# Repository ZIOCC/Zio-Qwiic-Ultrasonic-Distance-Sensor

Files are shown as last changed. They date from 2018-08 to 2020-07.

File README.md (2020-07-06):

# Zio Qwiic Ultrasonic Distance Sensor (HC-SR04)

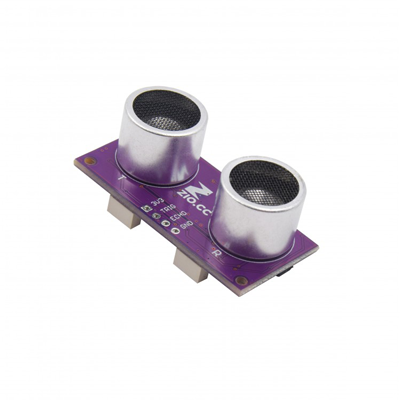
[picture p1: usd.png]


> This product can be available for purchase [here](https://www.smart-prototyping.com/Zio-Ultrasonic-Distance-Sensor.html).

#### Description

This is a [Qwiic](https://www.smart-prototyping.com/Qwiic.html) I2C version of ultrasonic sensor in our Qwiic family. TOF sensor is great, precise and fast, but this Ultrasonic sensor can provide wider detecting angle than TOF sensor and longer distance (3-400cm).

With this module we used a STM8 MCU as gateway to deal with sensor’s digital data in MCU, and send it out via I2C. So you don’t need to care about how it works inside the STM8, just trade it as an I2C device. In case you are interesting, you can check out the STM8 code at the bottom of the links.

We also break the serial pins just like the normal HC-SR04 module. The pins are not pre-soldered. We use an MCU (ATTINY85-20SU) as gateway to turn it into an I2C device.

For additional information on how the Ultrasonic sensor works, you can check out this [page](http://arduinoinfo.mywikis.net/wiki/UltraSonicDistance)!

Note: Try to avoid touching the pins and pads on the backside, the sensor measurement is based on analog single, touching these pins and pads will make the result unstable. 

#### Specification

* Operating Voltage: 3.3V
* Detecting Angle: 15 degree
* Sensor range: 2cm to 400cm
* Accuracy: 3mm
* MCU on board: STM8L051
* I2C Address: 0x00
* Dimension: 21.5x 45.5mm
* Weight: 9.2g

#### Links

* [Eagle File](https://github.com/ZIOCC/Zio-Qwiic-Ultrasonic-Distance-Sensor/)
* [Example Code](https://github.com/ZIOCC/Zio-Qwiic-Ultrasonic-Distance-Sensor/tree/master/Arduino)

###### About Zio
> Zio is a new line of open sourced, compact, and grid layout boards, fully integrated for Arduino and Qwiic ecosystem. Designed ideally for wearables, robotics, small-space limitations or other on the go projects. Check out other awesome Zio products [here](https://www.smart-prototyping.com/Zio).

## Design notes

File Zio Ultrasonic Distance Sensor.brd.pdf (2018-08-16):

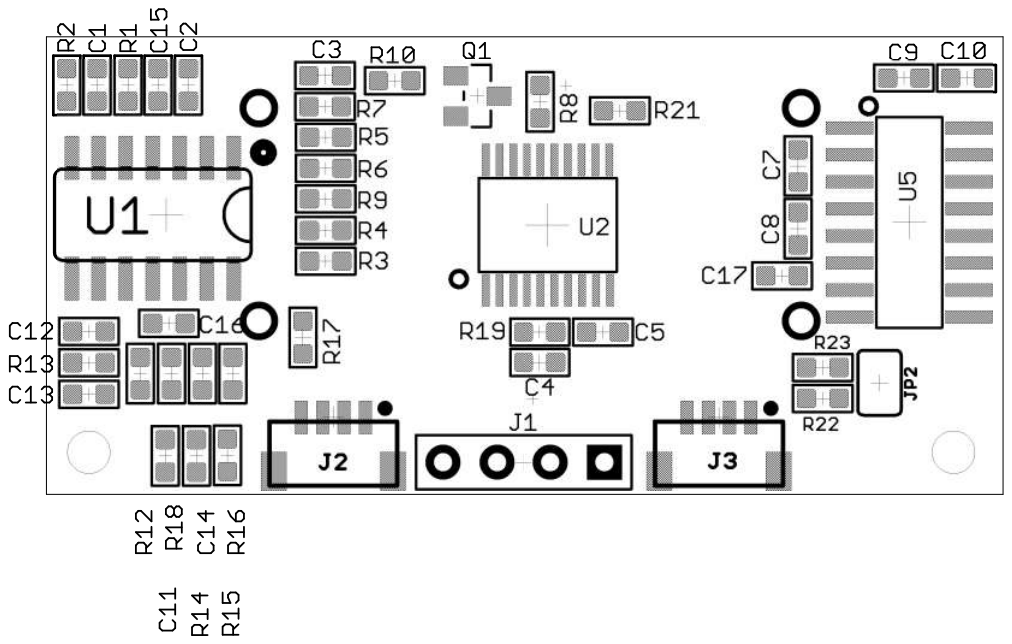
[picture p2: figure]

2018-07-04 19:09 f=3.00 D:\Webshop PCB\Zio Ultrasonic Distance Sensor\EAGLE\Zio Ultrasonic Distance Sensor.brd

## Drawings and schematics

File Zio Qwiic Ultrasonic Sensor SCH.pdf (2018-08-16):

# STM8 V⁺ V-

+3V3 1K ±1%

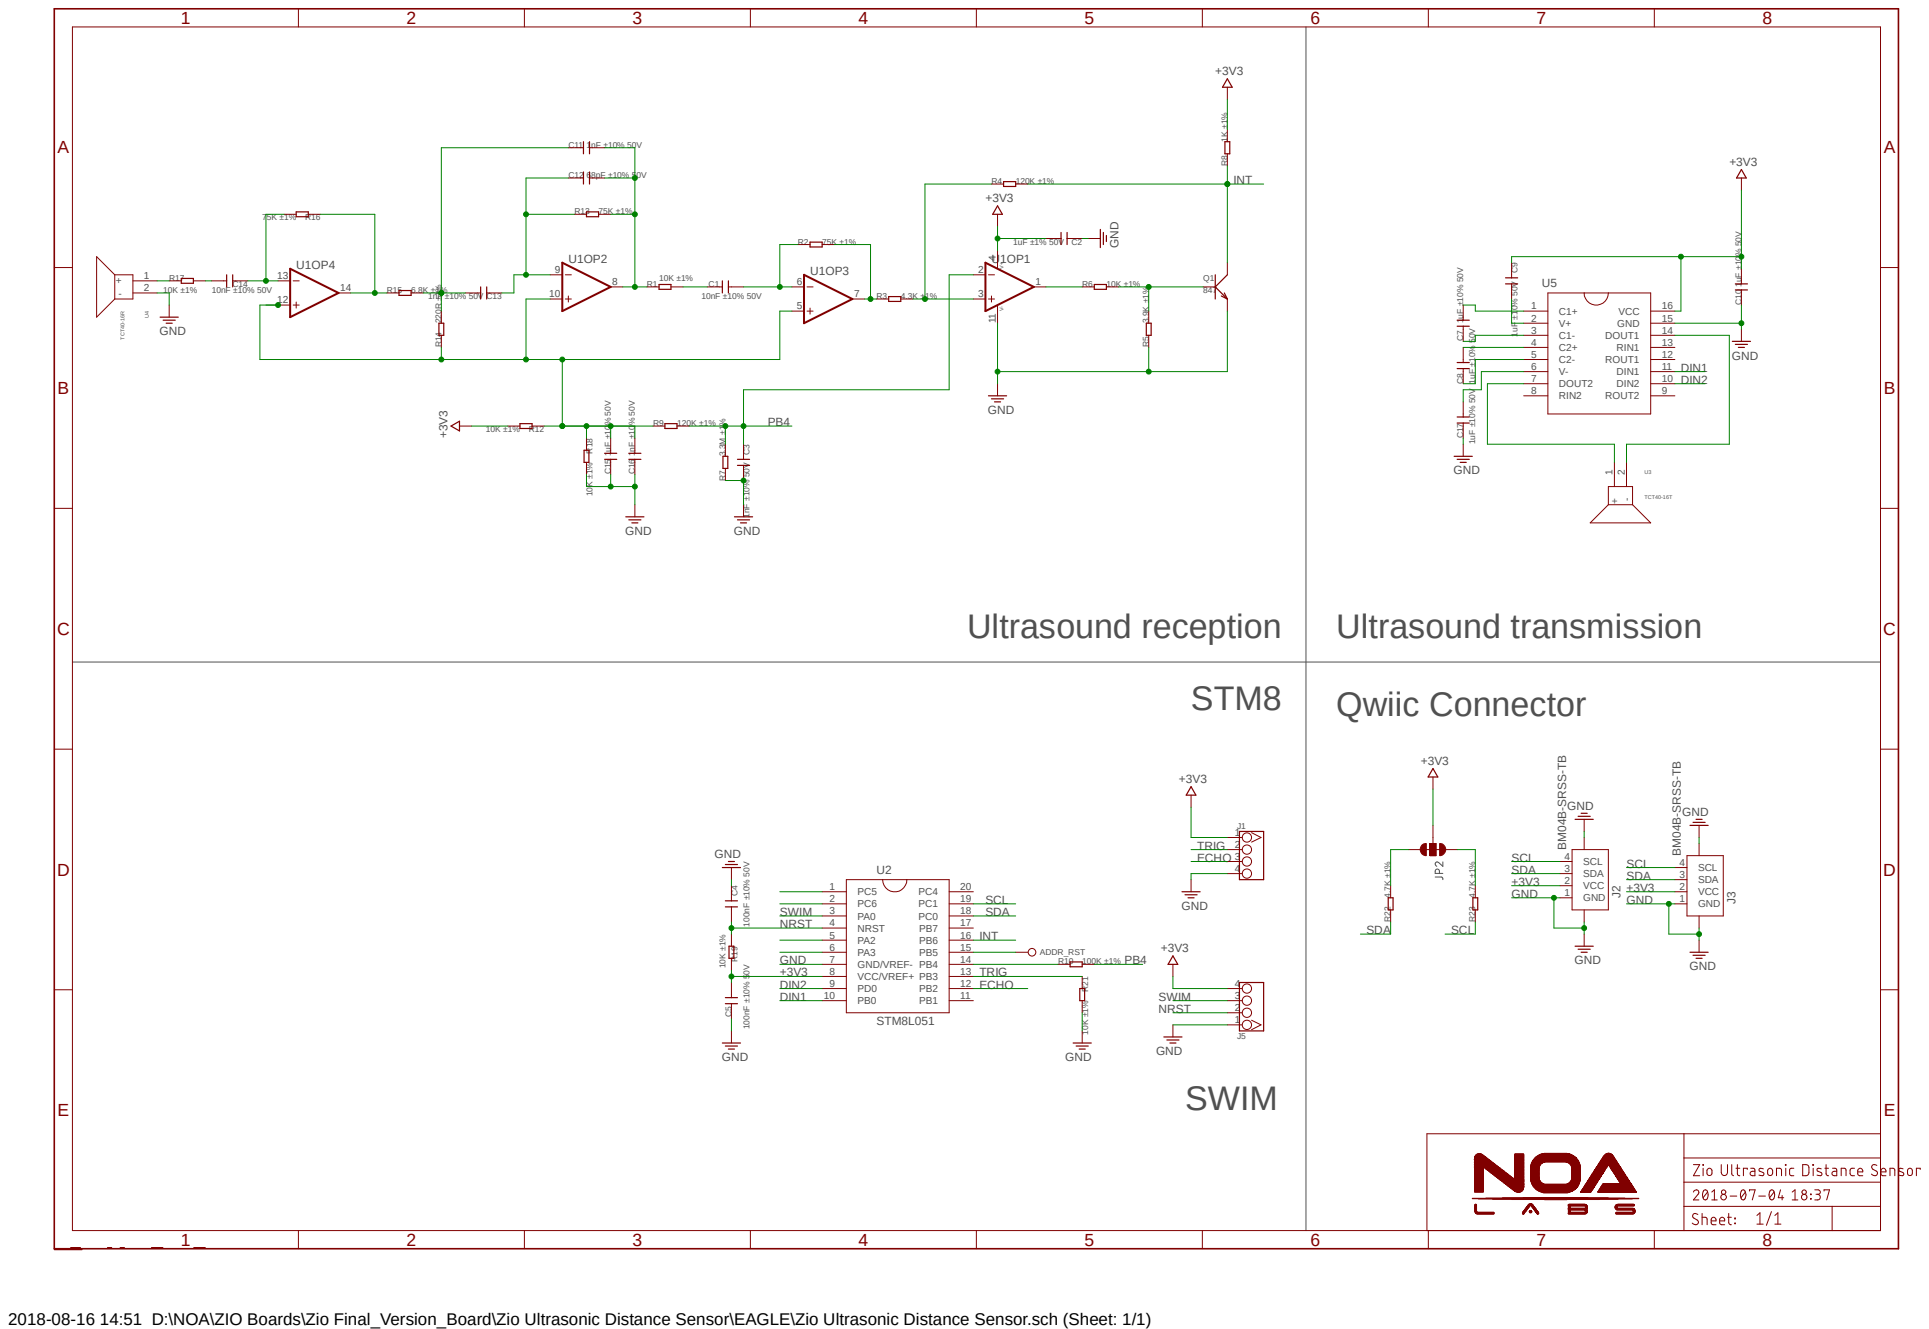
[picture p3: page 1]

2018-08-16 14:51 D:\NOA\ZIO Boards\Zio Final_Version_Board\Zio Ultrasonic Distance Sensor\EAGLE\Zio Ultrasonic Distance Sensor.sch (Sheet: 1/1)

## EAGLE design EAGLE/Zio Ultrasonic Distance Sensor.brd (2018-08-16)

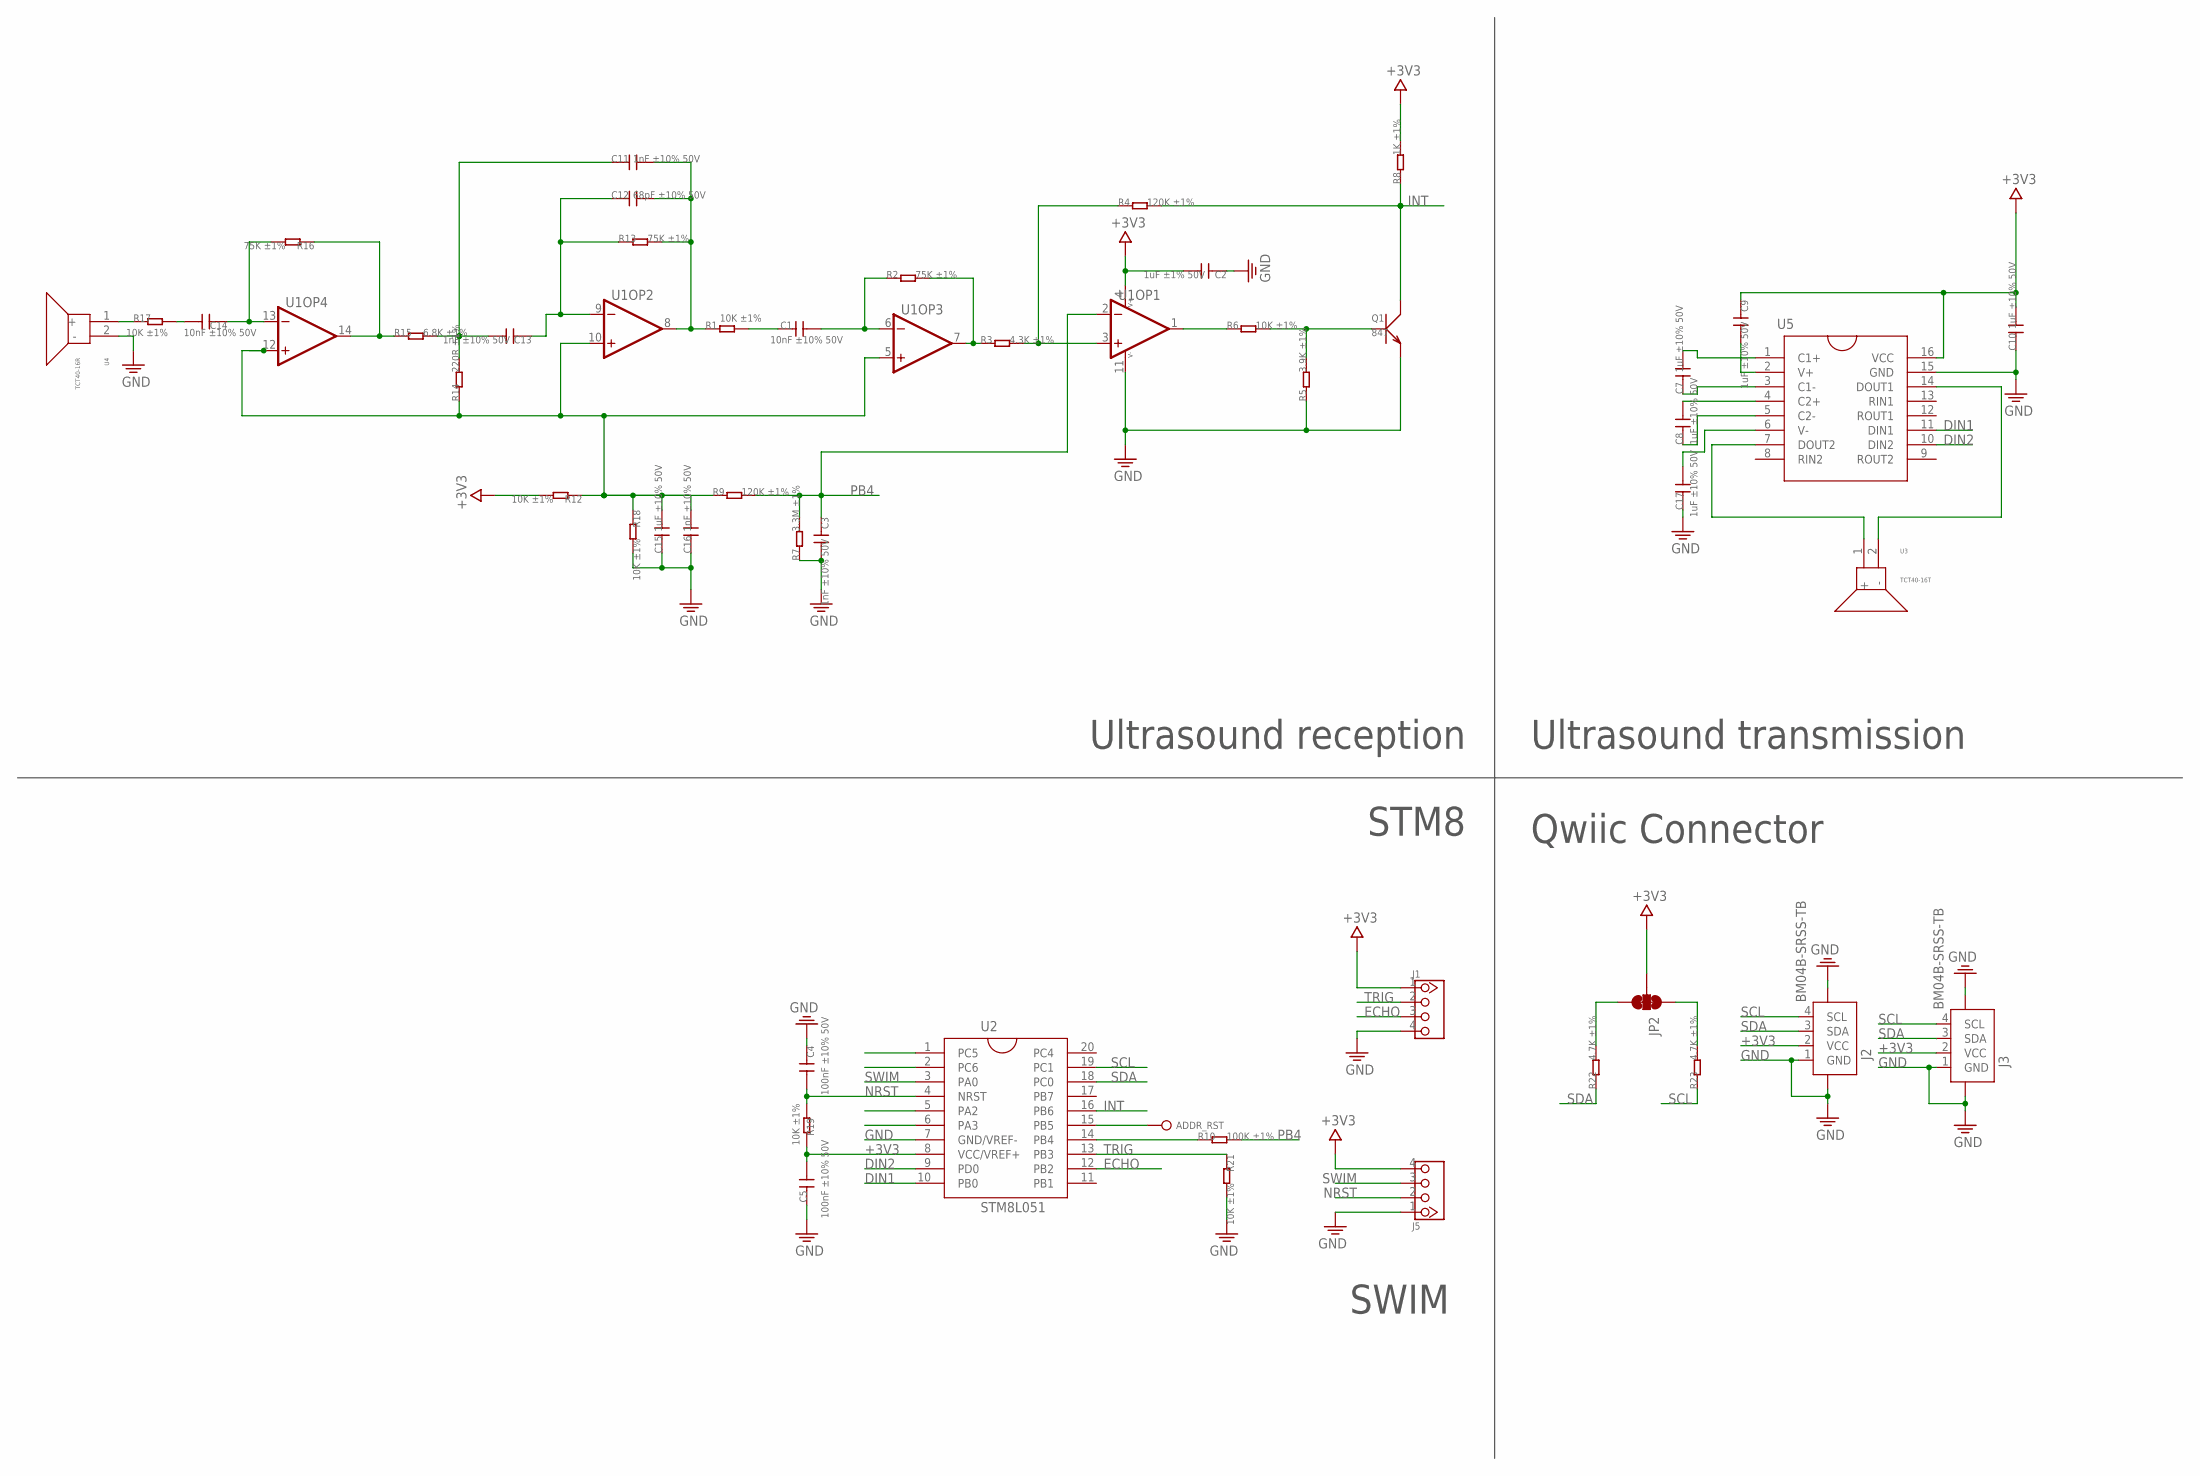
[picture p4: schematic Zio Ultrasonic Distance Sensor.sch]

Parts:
ADDR_RST: TEST_POINT35MIL; 1P-35MIL
C1, C14: 10nF ±10% 50V; 0603
C2: 1uF ±1% 50V; 0603
C3, C11, C13, C16: 1nF ±10% 50V; 0603
C4, C5: 100nF ±10% 50V; 0603
C7, C8, C9, C10, C15, C17: 1uF ±10% 50V; 0603
C12: 68pF ±10% 50V; 0603
J1: HEADER-4P-60/35MIL; 4P-65/35MIL
J2, J3: BM04B-SRSS-TB; JST-SH-4P-90
J5: HEADER-4P-TEST_3.08_4P; TEST_3.08_4P
JP2: SMT-JUMPER_3_2-NC_TRACE
Q1: 847; SOT23
R1, R6, R12, R17, R18, R19, R21: 10K ±1%; 0603
R2, R13, R16: 75K ±1%; 0603
R3: 4.3K ±1%; 0603
R4, R9: 120K ±1%; 0603
R5: 3.9K ±1%; 0603
R7: 3.3M ±1%; 0603
R8: 1K ±1%; 0603
R10: 100K ±1%; 0603
R14: 220R ±1%; 0603
R15: 6.8K ±1%; 0603
R22, R23: 4.7K ±1%; 0603
U1: LMV324; SO014
U2: STM8L051; TSSOP20
U3: TCT40-16T; TCT40-16T/R
U4: TCT40-16R; TCT40-16T/R
U5: UT3232G-S16-RSOIC-16; SOIC16

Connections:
+3V3: C2.2, C5.1, C9.1, C10.2, J1.1, J2.2 (VCC), J3.2 (VCC), J5.4, JP2.2, R8.2, R12.2, R19.2, U1.4 (V+), U2.8 (VCC/VREF+), U5.16 (VCC)
DIN1: U2.10 (PB0), U5.11 (DIN1)
DIN2: U2.9 (PD0), U5.10 (DIN2)
ECHO: J1.3, U2.12 (PB2)
GND: C2.1, C3.2, C4.1, C5.2, C10.1, C15.1, C16.1, C17.1, J1.4, J2.1 (GND), J2.5, J2.6, J3.1 (GND), J3.5, J3.6, J5.1, Q1.2 (E), R5.1, R7.1, R18.2, R21.2, U1.11 (V-), U2.7 (GND/VREF-), U4.2 (-), U5.15 (GND)
INT: Q1.3 (C), R4.2, R8.1, U2.16 (PB6)
unnamed: R2.2, R3.1, U1.7 (OUT)
unnamed: C1.1, R2.1, U1.6 (IN-)
unnamed: C1.2, R1.2
unnamed: R3.2, R4.1, U1.3 (IN+)
unnamed: Q1.1 (B), R5.2, R6.2
unnamed: R6.1, U1.1 (OUT)
unnamed: C7.2, U5.1 (C1+)
unnamed: C12.1, C13.1, R13.1, U1.9 (IN-)
unnamed: C11.2, C12.2, R1.1, R13.2, U1.8 (OUT)
unnamed: C15.2, C16.2, R9.1, R12.1, R14.1, R18.1, U1.5 (IN+), U1.10 (IN+), U1.12 (IN+)
unnamed: C11.1, C13.2, R14.2, R15.2
unnamed: C7.1, U5.3 (C1-)
unnamed: R15.1, R16.1, U1.14 (OUT)
unnamed: C14.1, R16.2, U1.13 (IN-)
unnamed: C14.2, R17.2
unnamed: C8.2, U5.4 (C2+)
unnamed: C8.1, U5.5 (C2-)
unnamed: JP2.3, R22.2
unnamed: JP2.1, R23.2
unnamed: C9.2, U5.2 (V+)
unnamed: C17.2, U5.6 (V-)
unnamed: U3.2 (-), U5.14 (DOUT1)
unnamed: U3.1 (+), U5.7 (DOUT2)
unnamed: R17.1, U4.1 (+)
unnamed: ADDR_RST.P$1, U2.15 (PB5)
unnamed: R10.1, U2.14 (PB4)
NRST: C4.2, J5.2, R19.1, U2.4 (NRST)
PB4: C3.1, R7.2, R9.2, R10.2, U1.2 (IN-)
SCL: J2.4 (SCL), J3.4 (SCL), R23.1, U2.19 (PC1)
SDA: J2.3 (SDA), J3.3 (SDA), R22.1, U2.18 (PC0)
SWIM: J5.3, U2.3 (PA0)
TRIG: J1.2, R21.1, U2.13 (PB3)

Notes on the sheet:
SWIM
Qwiic Connector
Ultrasound transmission
Ultrasound reception
STM8

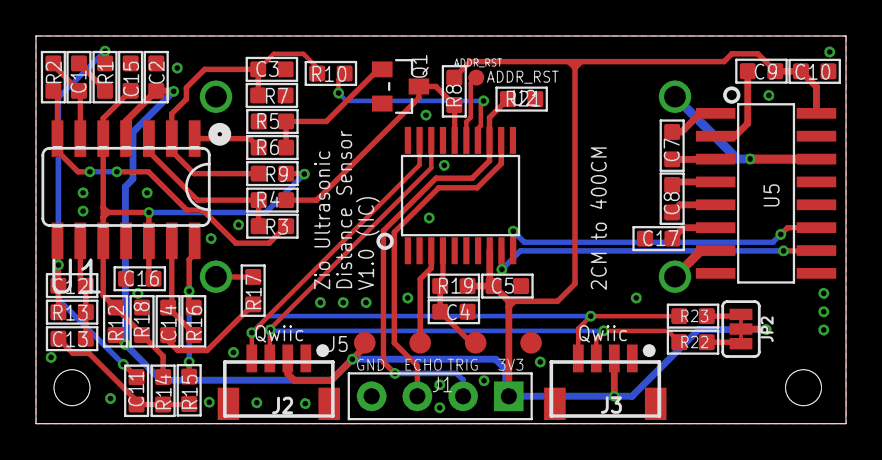
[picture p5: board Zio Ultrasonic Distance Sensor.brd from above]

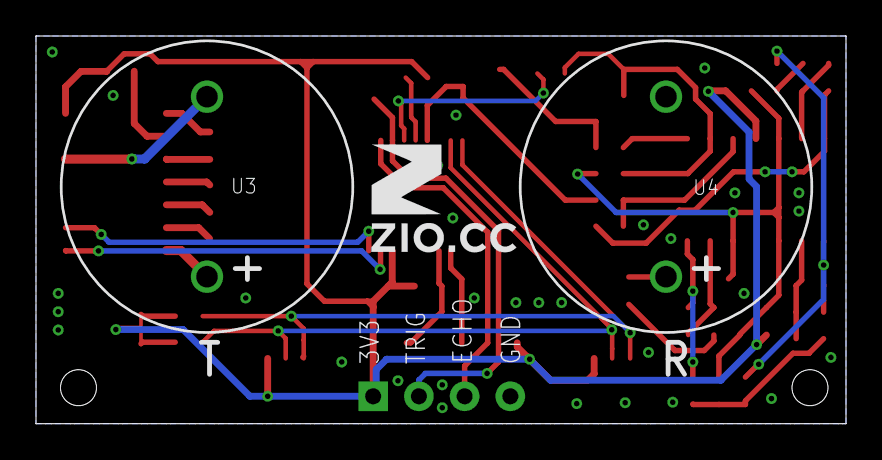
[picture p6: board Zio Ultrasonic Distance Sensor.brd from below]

Board: 2 copper layers, 45.0 x 21.5 mm, 50 parts (3 on the bottom side), 38 nets.

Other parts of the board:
U$5: 6MM

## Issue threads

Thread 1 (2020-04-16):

i2C Address

safariace, 2020-04-16:
I'm using a Raspberry Pi connected to a ZIO Ultrasonic with a qwiic connection.

I2CDetect returns no scan for the HC_SR04.  I see the other i2c devices on the bus, but no the ultrasonic sensor.  The arduino code has these two lines:

#define SLAVE_BROADCAST_ADDR 0x00  //default address
#define SLAVE_ADDR 0x00       //SLAVE_ADDR 0xA0-0xAF

Which implies address 0x00

The comment seems to imply the slave address should be in the range 0xA0-AF  .

AlexChuSmartPrototyping, 2020-06-17:
Hi, the sensor default address is 0x00, this is correct, you can just send the read commend to this address then you will get the distance data. There is way to change the sensor address, but unless there is address conflict, I won't recommend to do so.

JamesB7, 2021-07-15:
A sensor should never use address 0x00. It is reserved for I2C General Calls, which by spec may be used by some devices to configure their addresses (such devices will always be listening on 0x00 as well as their current address).

marvinrobot42, 2024-03-24:
I agree with JamesB7 in that the I2C sensor interface needs its own address, not 0x00 which is the "any address" or broadcast to all devices on bus address.  Hopefully Sparkfun can help with getting your own I2C address.

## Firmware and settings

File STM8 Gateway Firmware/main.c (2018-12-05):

/*******************************************************************************
***********************Zio Ultrasonic Distance Sensor***************************
***********************************ZIO.CC***************************************
*******************************************************************************/



#include "stm8l15x.h"
#include "bsp.h"

#define TIM4_PERIOD       16*10

//#define SLAVE_ADDR 0x00
#define I2CSPEED 400000 //i2c Speed

//extern uint8_t SLAVE_ADDRESS[10]={0xA0,0xA1,0xA2,0xA3,0xA4,0xA5,0xA6,0xA7,0xA8,0xA9};
extern uint8_t SLAVE_ADDRESS=0x00;

extern char SBUF=0;
extern uint16_t measure_flag=0;


/*******************************************************************************
****Parameter In£ºNone
****Parameter Out£ºNone
****Fuction£ºmain
****Author£ºHarry
*******************************************************************************/
int main( void )
{
  CLK_SYSCLKDivConfig(CLK_SYSCLKDiv_1);    
  CLK_SYSCLKSourceConfig(CLK_SYSCLKSource_HSI);
  CLK_HSICmd(ENABLE);                      
  
  GPIO_Init(GPIOB, (GPIO_Pin_TypeDef)GPIO_Pin_0, GPIO_Mode_Out_PP_Low_Fast);
  GPIO_Init(GPIOD, (GPIO_Pin_TypeDef)GPIO_Pin_0, GPIO_Mode_Out_PP_Low_Fast);
  GPIO_Init(GPIOB, (GPIO_Pin_TypeDef)GPIO_Pin_2, GPIO_Mode_Out_PP_Low_Fast);
  GPIO_Init(GPIOB, (GPIO_Pin_TypeDef)GPIO_Pin_4, GPIO_Mode_Out_PP_Low_Fast);
  
  GPIO_Init(GPIOC, (GPIO_Pin_TypeDef)GPIO_Pin_0, GPIO_Mode_Out_PP_High_Fast);
  GPIO_Init(GPIOC, (GPIO_Pin_TypeDef)GPIO_Pin_1, GPIO_Mode_Out_PP_High_Fast);

  GPIO_Init(GPIOB, (GPIO_Pin_TypeDef)GPIO_Pin_3, GPIO_Mode_In_FL_IT);
  GPIO_Init(GPIOB, (GPIO_Pin_TypeDef)GPIO_Pin_6, GPIO_Mode_In_FL_IT);
  GPIO_Init(GPIOB, (GPIO_Pin_TypeDef)GPIO_Pin_5, GPIO_Mode_In_PU_IT);
  
  EXTI_DeInit (); 
  EXTI_SetPinSensitivity (EXTI_Pin_3,EXTI_Trigger_Rising);
  EXTI_SetPinSensitivity (EXTI_Pin_6,EXTI_Trigger_Rising);
  EXTI_SetPinSensitivity (EXTI_Pin_5,EXTI_Trigger_Falling);
  
  
  CLK_PeripheralClockConfig(CLK_Peripheral_TIM2,ENABLE);         
  TIM2_DeInit();    
  TIM2_TimeBaseInit(TIM2_Prescaler_8, TIM2_CounterMode_Up, 65535);         
  TIM2_ARRPreloadConfig(ENABLE);    
  TIM2_ITConfig(TIM2_IT_Update, ENABLE);
//  TIM2_Cmd(ENABLE);


  CLK_PeripheralClockConfig(CLK_Peripheral_TIM3,ENABLE);         
  TIM3_DeInit();    
  TIM3_TimeBaseInit(TIM3_Prescaler_128, TIM3_CounterMode_Up, 5500); 
  TIM3_ARRPreloadConfig(ENABLE);    
  TIM3_ITConfig(TIM3_IT_Update, ENABLE);    
//  TIM3_Cmd(ENABLE); 
  
  CLK_PeripheralClockConfig (CLK_Peripheral_TIM4,ENABLE); 
  TIM4_DeInit();
  TIM4_TimeBaseInit(TIM4_Prescaler_128, TIM4_PERIOD);
  TIM4_ARRPreloadConfig(ENABLE);
  TIM4_ITConfig(TIM4_IT_Update, ENABLE);
//  TIM4_Cmd(ENABLE);
  
  FLASH_DeInit();

  
    /* I2C  clock Enable*/
  CLK_PeripheralClockConfig(CLK_Peripheral_I2C1, ENABLE);
  I2C_DeInit_Config(EEPROM_ReadByte(0));
  GPIO_SetBits(GPIOB,GPIO_Pin_4);
  enableInterrupts();

   
  while(1)
  {

  }
    
    
}

/*******************************************************************************
***********************Zio Ultrasonic Distance Sensor***************************
***********************************ZIO.CC***************************************
*******************************************************************************/

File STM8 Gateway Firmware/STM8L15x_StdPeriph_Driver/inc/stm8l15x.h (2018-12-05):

/**
  ******************************************************************************
  * @file    stm8l15x.h
  * @author  MCD Application Team
  * @version V1.5.0
  * @date    13-May-2011
  * @brief   This file contains all the peripheral register's definitions, bits
  *          definitions and memory mapping for STM8L15x devices.
  ******************************************************************************
  * @attention
  *
  * THE PRESENT FIRMWARE WHICH IS FOR GUIDANCE ONLY AIMS AT PROVIDING CUSTOMERS
  * WITH CODING INFORMATION REGARDING THEIR PRODUCTS IN ORDER FOR THEM TO SAVE
  * TIME. AS A RESULT, STMICROELECTRONICS SHALL NOT BE HELD LIABLE FOR ANY
  * DIRECT, INDIRECT OR CONSEQUENTIAL DAMAGES WITH RESPECT TO ANY CLAIMS ARISING
  * FROM THE CONTENT OF SUCH FIRMWARE AND/OR THE USE MADE BY CUSTOMERS OF THE
  * CODING INFORMATION CONTAINED HEREIN IN CONNECTION WITH THEIR PRODUCTS.
  *
  * <h2><center>&copy; COPYRIGHT 2011 STMicroelectronics</center></h2>
  ******************************************************************************  
  */

/* Define to prevent recursive inclusion -------------------------------------*/
#ifndef __STM8L15x_H
 #define __STM8L15x_H

/** @addtogroup STM8L15x_StdPeriph_Driver
  * @{
  */
/* Uncomment the line below according to the target STM8L15x device used in your
   application
  */
/* #define STM8L15X_LD */     /*!< STM8L15X_LD: STM8L15x Low density devices */
 #define STM8L15X_MD */     /*!< STM8L15X_MD: STM8L15x Medium density devices */
/* #define STM8L15X_MDP */    /*!< STM8L15X_MDP: STM8L15x Medium density plus devices */
/* #define STM8L15X_HD */    /*!< STM8L15X_HD: STM8L15x/16x High density devices */

/*  Tip: To avoid modifying this file each time you need to switch between these
        devices, you can define the device in your toolchain compiler preprocessor.

 - Low density STM8L15x devices are STM8L151C3, STM8L151K3, STM8L151G3, STM8L151F3,
   STM8L151C2, STM8L151K2, STM8L151G2 and STM8L151F2 microcontrollers where the 
   Flash memory density ranges between 4 and 8 Kbytes.
 - Medium density STM8L15x devices are STM8L151C4, STM8L151C6, STM8L152C4,
   STM8L152C6, STM8L151K4, STM8L151K6, STM8L152K4, STM8L152K6, STM8L151G4,
   STM8L151G6, STM8L152G4 and STM8L152G6 microcontrollers where the Flash memory
   density ranges between 16 and 32 Kbytes.
 - Medium density Plus devices are STM8L151R6, STM8L152R6 microcontrollers where
  the Flash memory density is fixed and equal to 32 Kbytes and a wider range of
  peripheral than the medium density devices.
 - High density STM8L15x devices are STM8L151x8, STM8L152x8, STM8L162R8 and STM8L162M8
   microcontrollers where the Flash memory density is fixed and equal to 64 Kbytes with 
   the same peripheral set than Medium Density Plus devices.

 */

#if !defined (STM8L15X_MD) && !defined (STM8L15X_MDP) && !defined (STM8L15X_HD) && !defined (STM8L15X_LD)
 #error "Please select first the target STM8L device used in your application (in stm8l15x.h file)"
#endif

/******************************************************************************/
/*                   Library configuration section                            */
/******************************************************************************/
/* Check the used compiler */
#if defined(__CSMC__)
 #define _COSMIC_
#elif defined(__RCST7__)
 #define _RAISONANCE_
#elif defined(__ICCSTM8__)
 #define _IAR_
#else
 #error "Unsupported Compiler!"          /* Compiler defines not found */
#endif

#if !defined  USE_STDPERIPH_DRIVER
/* Comment the line below if you will not use the peripherals drivers.
   In this case, these drivers will not be included and the application code will be
   based on direct access to peripherals registers */
 #define USE_STDPERIPH_DRIVER
#endif

/**
 * @brief In the following line adjust the value of External High Speed oscillator (HSE)
   used in your application

   Tip: To avoid modifying this file each time you need to use different HSE, you
        can define the HSE value in your toolchain compiler preprocessor.
  */
#if !defined  HSE_Value
 #define HSE_VALUE   ((uint32_t)16000000) /*!< Typical Value of the HSE in Hz */
#endif /* HSE_Value */

/**
  * @brief Definition of External Low Speed oscillator (LSE) frequency
  */
#define LSE_VALUE   ((uint32_t)32768)   /*!< Typical Value of the LSE in Hz */

/**
  * @brief Definition of Device on-chip RC oscillator frequencies
  */
#define HSI_VALUE   ((uint32_t)16000000) /*!< Typical Value of the HSI in Hz */
#define LSI_VALUE   ((uint32_t)38000)    /*!< Typical Value of the LSI in Hz */

#ifdef _COSMIC_
 #define FAR  @far
 #define NEAR @near
 #define TINY @tiny
 #define EEPROM @eeprom
 #define CONST  const
#elif defined (_RAISONANCE_) /* __RCST7__ */
 #define FAR  far
 #define NEAR data
 #define TINY page0
 #define EEPROM eeprom
 #define CONST  code
 #if defined (STM8L15X_MD) || defined (STM8L15X_MDP)
  /*!< Used with memory Models for code less than 64K */
  #define MEMCPY memcpy
 #else /* STM8L15X_HD */
   /*!< Used with memory Models for code higher than 64K */
  #define MEMCPY fmemcpy
 #endif /* STM8L15X_MD or STM8L15X_MDP */ 
#else /*_IAR_*/
 #define FAR  __far
 #define NEAR __near
 #define TINY __tiny
 #define EEPROM __eeprom
 #define CONST  const
#endif /* __CSMC__ */

/**
  * @brief Legacy definition
  */
#define __CONST  CONST

#if defined (STM8L15X_MD) || defined (STM8L15X_MDP) || defined (STM8L15X_LD) 
/*!< Used with memory Models for code smaller than 64K */
 #define PointerAttr NEAR
#else /* STM8L15X_HD */
/*!< Used with memory Models for code higher than 64K */
 #define PointerAttr FAR
#endif /* STM8L15X_MD or STM8L15X_MDP or STM8L15X_LD*/

/* Uncomment the line below to enable the FLASH functions execution from RAM */
#if !defined (RAM_EXECUTION)
/* #define RAM_EXECUTION  (1) */
#endif /* RAM_EXECUTION */

#ifdef RAM_EXECUTION
 #ifdef _COSMIC_
   #define IN_RAM(a) a
 #elif defined (_RAISONANCE_) /* __RCST7__ */
   #define IN_RAM(a) a inram
 #else /*_IAR_*/
  #define IN_RAM(a) __ramfunc a
 #endif /* _COSMIC_ */
#else 
  #define IN_RAM(a) a
#endif /* RAM_EXECUTION */

/*!< [31:16] STM8L15X Standard Peripheral Library main version */
#define __STM8L15X_STDPERIPH_VERSION_MAIN   ((uint8_t)0x01) /*!< [31:24] main version */                                  
#define __STM8L15X_STDPERIPH_VERSION_SUB1   ((uint8_t)0x05) /*!< [23:16] sub1 version */
#define __STM8L15X_STDPERIPH_VERSION_SUB2   ((uint8_t)0x00) /*!< [15:8]  sub2 version */
#define __STM8L15X_STDPERIPH_VERSION_RC     ((uint8_t)0x00) /*!< [7:0]  release candidate */ 
#define __STM8L15X_STDPERIPH_VERSION       ( (__STM8L15X_STDPERIPH_VERSION_MAIN << 24)\
                                          |(__STM8L15X_STDPERIPH_VERSION_SUB1 << 16)\
                                          |(__STM8L15X_STDPERIPH_VERSION_SUB2 << 8)\
                                          |(__STM8L15X_STDPERIPH_VERSION_RC))

/******************************************************************************/
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

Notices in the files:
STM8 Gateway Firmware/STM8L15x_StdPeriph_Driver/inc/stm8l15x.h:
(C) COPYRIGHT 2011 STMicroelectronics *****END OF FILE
